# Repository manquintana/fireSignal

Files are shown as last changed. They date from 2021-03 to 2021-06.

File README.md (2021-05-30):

fireSignal
Author: Manuel Alejandro Quintana
MGUNTECH 2021

## Introduccion

fireSignal es un dispositivo de hardware desarrollado para permitir la práctica de tiro rápido en varias modalidades, seteando previo a cada tanda de disparos, un temporizador que indicará al tirador en qué momento comenzar a disparar y cuando dejar de hacerlo.
- Permite setear tandas entre 1 segundo y 99 minutos.
- Cuenta con dos indicadores: uno lumínico y otro sonoro.
- Es muy cómodo para utilizar en polígonos que no cuenten con un sistema automatizado de blancos por ejemplo para practicar tiro FBI.
- Además, no hay necesidad de contar con un instructor asistente.

## Requisitos

Para construir el dispositivo, hay que valerse de:

Hardware: 
- Arduino Nano V3 CH340 (x2)
- nrf24l01 Module (x2)
- Powerbank 5V 1A (x2)
- Matriz led 8x8 controlador Max 7219
- Beeper 3 pins
- pulsador de 4 patas (x3)
- display 7 segmentos 4 digitos controlador Tm1637
- impresora 3d para imprimir la carcaza
- cables de conexión
- placa de prototipado

Software:
- Arduino IDE

## Construccion

Consultar esquema de construcción publicado

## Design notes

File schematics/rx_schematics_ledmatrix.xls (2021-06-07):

Pin 15188AS | 8 | 7 | 6 | 5 | 4 | 3 | 2 | 1
Pin Arduino | A4 |  | 5 | A3 |  | 4 |  | A2
 |  |  | 6 | A5 |  |  | 7
 | 9 | 10 | 11 | 12 | 13 | 14 | 15 | 16
Los pines puenteados en rojo son los ánodos deben puentearse y luego agregar una resistencia de 330ohm antes de conectar a Arduino
Los pines puenteados en amarillo son los cátodos, simplemente se puentean y se conectan a Arduino sin resistencia.
Nota: El lado con el sello 1588 es el lado de los leds 1 a 8.

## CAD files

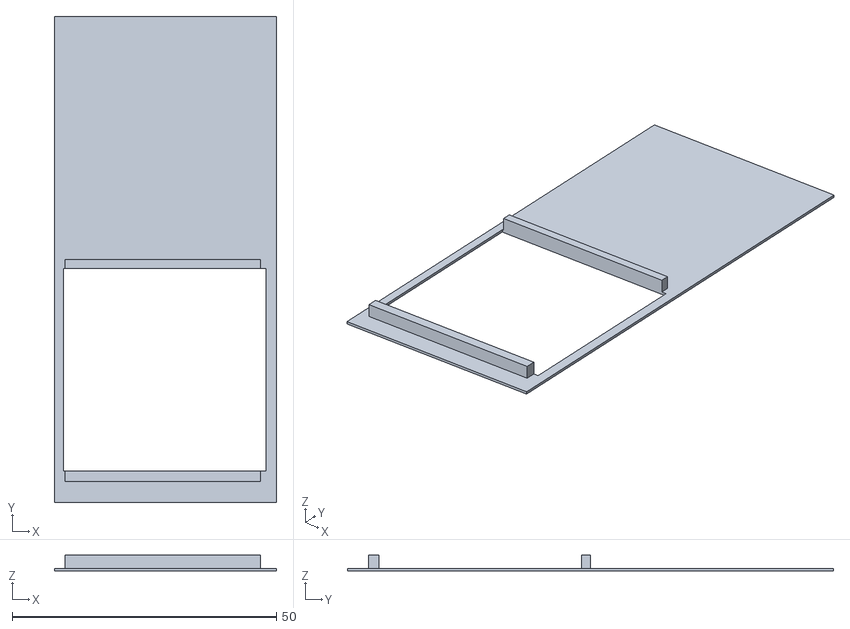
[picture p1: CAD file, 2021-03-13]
stl_files/RX/rx-part2 SUPPORT.stl
42.0 x 92.0 x 3.00

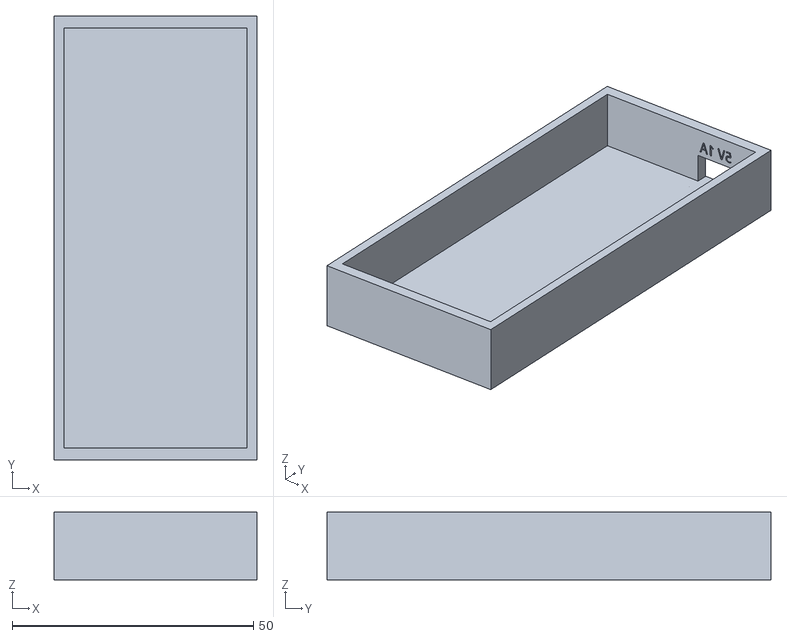
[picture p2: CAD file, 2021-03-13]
stl_files/RX/rx-part3 BASE.stl
42.0 x 92.0 x 14.0

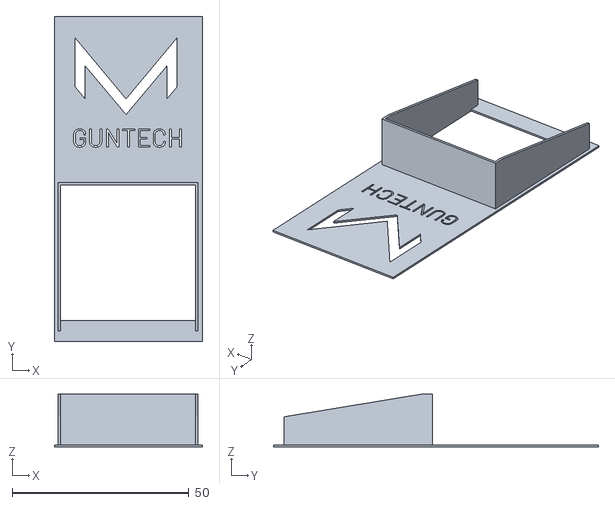
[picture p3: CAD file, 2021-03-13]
stl_files/RX/rx-part1 TOP.stl
42.0 x 92.0 x 15.0

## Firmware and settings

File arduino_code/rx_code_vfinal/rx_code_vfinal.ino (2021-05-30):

#include <SPI.h>
#include <nRF24L01.h>
#include <RF24.h>



//Rows
#define R1 A2
#define R2 A3
#define R3 A4
#define R4 A5
//Columns
#define C1 4
#define C2 5
#define C3 6
#define C4 7

// RF24
#define CE_PIN 9
#define CSN_PIN 10
byte direccion[5] ={'m','a','n','u','1'};  //canal de tx-rx
RF24 radio(CE_PIN, CSN_PIN);
int datos[1];//vector con los datos recibido


void setup() {
  Serial.begin(9600);
  
  radio.begin(); //Inicializacion rf24l01
  radio.openReadingPipe(1, direccion);
  radio.startListening();
   
  pinMode(R1, OUTPUT);
  pinMode(R2, OUTPUT);
  pinMode(R3, OUTPUT);
  pinMode(R4, OUTPUT);
   
  pinMode(C1, OUTPUT);
  pinMode(C2, OUTPUT);
  pinMode(C3, OUTPUT);
  pinMode(C4, OUTPUT);
  
// Turning all the LEDs off at the start of the sketch
  turnOnAll();
  
}

void selectRow(int row){
  if (row==1) digitalWrite(R1,LOW); else digitalWrite(R1,HIGH);
  if (row==2) digitalWrite(R2,LOW); else digitalWrite(R2,HIGH);
  if (row==3) digitalWrite(R3,LOW); else digitalWrite(R3,HIGH);
  if (row==4) digitalWrite(R4,LOW); else digitalWrite(R4,HIGH);
}

void selectColumn(int column){
  if (column==1) digitalWrite(C1,HIGH); else digitalWrite(C1,LOW);
  if (column==2) digitalWrite(C2,HIGH); else digitalWrite(C2,LOW);
  if (column==3) digitalWrite(C3,HIGH); else digitalWrite(C3,LOW);
  if (column==4) digitalWrite(C4,HIGH); else digitalWrite(C4,LOW);
}

void turnOnAll(){
  digitalWrite(R1,LOW);
  digitalWrite(R2,LOW);
  digitalWrite(R3,LOW);
  digitalWrite(R4,LOW);
  
  digitalWrite(C1,HIGH);
  digitalWrite(C2,HIGH);
  digitalWrite(C3,HIGH);
  digitalWrite(C4,HIGH);
}

void turnOffAll(int tiempo){
  Serial.print("START initial time:");
  Serial.println(tiempo);
  while (tiempo > 0){
    digitalWrite(R1,HIGH);
    digitalWrite(R2,HIGH);
    digitalWrite(R3,HIGH);
    digitalWrite(R4,HIGH);
    digitalWrite(C1,LOW);
    digitalWrite(C2,LOW);
    digitalWrite(C3,LOW);
    digitalWrite(C4,LOW);
    
    Serial.println(tiempo);
    tiempo= tiempo - 1;
    delay(1000);
  }
  turnOnAll();
}



void loop() {
  if (radio.available()){
    radio.read(datos,sizeof(datos));
    switch (datos[0]){
      case 0:
        Serial.println(datos[0]);
        turnOnAll();
        break;
      default:
        Serial.print("disparar: ");
        Serial.println(datos[0]);
        turnOffAll(datos[0]);
        break;
    }
  } 
  
  delay(100);
}

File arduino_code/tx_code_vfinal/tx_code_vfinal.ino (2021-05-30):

#include <SPI.h>
#include <nRF24L01.h>
#include <RF24.h>

#include <TM1637Display.h>

/* TM1637 Display */
TM1637Display display(4,3);
const uint8_t OFF[] = {0, 0, 0, 0};

/* Buttons + Buzzer */
int count = 0;
const int pBuzzer = 2;
const int pButtonUp = 8;
const int pButtonDown = 7;
const int pButtonSend = 5;

/*NRF24*/
#define CE_PIN 9
#define CSN_PIN 10
byte direccion[5] ={'m','a','n','u','1'}; //canal de tx-rx
RF24 radio(CE_PIN, CSN_PIN);
int datos[1];//vector con los datos a enviar

void setup() {
  radio.begin();
  radio.openWritingPipe(direccion);
  
  Serial.begin(9600);

  //TM1637
  display.setBrightness(10);
  display.setSegments(OFF);
  display.showNumberDecEx(0, 0, true, 2, 2);
  display.showNumberDecEx(0, 0x40, true, 2, 0);
  
  //Buttons
  pinMode(pButtonUp, INPUT);
  digitalWrite(pButtonUp, HIGH); // connect internal pull-up
  pinMode(pButtonDown, INPUT);
  digitalWrite(pButtonDown, HIGH);
  pinMode(pButtonSend, INPUT);
  digitalWrite(pButtonSend, HIGH);

}


void calculateTime() {
  int seconds = count;
  int minutes = 0;
  while (seconds > 59) {
    minutes++;
    seconds = seconds - 60;
  }
  //Serial.println("minutos:");
  //Serial.println(minutes);
  //Serial.println("segundos:");
  //Serial.println(seconds);

  display.showNumberDecEx(seconds, 0, true, 2, 2);
  display.showNumberDecEx(minutes, 0x40, true, 2, 0);
}

void startCountDown(){
  while(count > 0){
    count--;
    calculateTime();
    if (count == 0){
      digitalWrite(pBuzzer, 150);
      delay(800);
      digitalWrite(pBuzzer, LOW);
    }
    delay(1000);
  }
}

boolean buttonPressed(int pin)
{
  int button_pressed = !digitalRead(pin); // pin low -> pressed
  return button_pressed;
}


void loop() {

  if (buttonPressed(pButtonUp)) {
    if (count < 3541) {
      count = count + 1;
    }
    calculateTime();
  }

  if (buttonPressed(pButtonDown)) {
    if (count > 0) {
      count = count - 1;
    } else {
      count = 0;
    }
    calculateTime();
  }

  //Serial.println(count);

  // BUZZER CONTROL
  if (buttonPressed(pButtonSend)) {
    if (count != 0){              //Si hay tiempo seteado
      digitalWrite(pBuzzer, 150);
      delay(800);
      digitalWrite(pBuzzer, LOW);
      delay(3000);
      for (int beeps = 0; beeps < 3; beeps++) {
        digitalWrite(pBuzzer, 150);
        delay(200);
        digitalWrite(pBuzzer, LOW);
        delay(800);
      }
      digitalWrite(pBuzzer, LOW);
      
      
      //Envia numero de segundos para apagar la luz!
      datos[0]=count;
      bool ok = radio.write(datos, sizeof(datos));
      while (!ok){
        Serial.println("No se ha podido enviar. Reenviando...");
        ok = radio.write(datos, sizeof(datos));
        delay(200);
      }
      Serial.print("Datos enviados: ");
      Serial.println(datos[0]);
      startCountDown();
      
      
      
    }
    else{                         // Codigo de error si no hay tiempo seteado
      digitalWrite(pBuzzer, 150);
      delay(50);
      digitalWrite(pBuzzer, LOW);
      delay(50);
      digitalWrite(pBuzzer, 150);
      delay(50);
      digitalWrite(pBuzzer, LOW);
      delay(50);
    }
    
  }
  else{
    //Envia codigo 0 para prender la luz!
    datos[0]=0;
    bool ok = radio.write(datos, sizeof(datos));
    while (!ok){
      Serial.println("No se ha podido enviar. Reenviando...");
      ok = radio.write(datos, sizeof(datos));
      delay(200);
    }
    Serial.print("Datos enviados: ");
    Serial.println(datos[0]);
  }

  // sleep a moment before next iteration
  delay(120);

}

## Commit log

2021-03-13 Initial commit (prototype files working fine)
    Vamos!!!!!
    [rx-part1 TOP.stl, rx-part2 SUPPORT.stl, rx-part3 BASE.stl]
2021-05-29 Project ready for publication
    [rx-part1 TOP.stl, rx-part2 SUPPORT.stl, rx-part3 BASE.stl]
2021-06-07 Added schematics folder, firstcommit
    [tx_schematics.fzz]
2021-06-07 Added RX schematics and connection table
    [rx_schematics.fzz, rx_schematics_ledmatrix.xls, tx_schematics.fzz]
